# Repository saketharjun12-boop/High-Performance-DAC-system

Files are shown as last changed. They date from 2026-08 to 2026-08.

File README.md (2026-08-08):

# High-Performance Mixed-Signal Headphone DAC

**AK4191EQ + AK4499EX + ESP32-S3 | KiCad | Low-Noise Power | High-Impedance Headphones**

A custom mixed-signal headphone DAC/amplifier designed around the **AK4191EQ digital modulator** and **AK4499EX DAC**, with a focus on low-noise analog power, current-to-voltage conversion, differential analog processing, and high-impedance headphone drive.

> **Project status:** PCB routing is **not complete**. Routing is currently complete **through Stage 2 only**. Later analog/output and remaining power-routing sections are still in progress.

---

## Project Overview

Primary signal chain:

```text
Digital Source
    |
AK4191EQ Digital Modulator
    |
AK4499EX DAC
    |
OPA1612 I/V Conversion
    |
Low-Pass / Differential Summing
    |
OPA1622 Headphone Driver
    |
Output Mute Relay
    |
6.35 mm TRS Headphone Jack
```

Control is provided by an **ESP32-S3**, including I2C configuration and future power-sequencing / relay-control functionality.

---

## Main Components

| Function | Component |
|---|---|
| Digital modulator | AK4191EQ |
| DAC | AK4499EX |
| Controller | ESP32-S3 |
| I/V conversion | OPA1612 |
| Headphone output stage | OPA1622 |
| 5 V to 5.8 V boost | TPS610891 |
| Ultra-low-noise 5VA LDO | LT3045 |
| Bipolar analog supply | TPS65131 |
| Output muting | DPDT relay |
| Output connector | 6.35 mm TRS jack |

---

## Current Project Status

- [x] Overall architecture defined
- [x] Major components selected
- [x] AK4191EQ / AK4499EX architecture
- [x] I/V conversion stage
- [x] Differential / headphone output stage
- [x] Relay-based output mute
- [x] 5VA power architecture
- [x] +/-15 V rail architecture
- [x] Initial power budget
- [x] TPS610891 design calculations
- [x] LT3045 calculations
- [x] Initial +/-15 V / headphone-load budget
- [x] Initial trace-width and via-sizing methodology
- [x] PCB routing through **Stage 3**
- [ ] Remaining PCB routing
- [ ] Final ERC / DRC
- [ ] Final BOM freeze
- [ ] Gerber generation
- [ ] Fabrication
- [ ] Assembly
- [ ] Board bring-up
- [ ] Electrical validation
- [ ] Audio measurements

---

# Power Architecture

```text
USB-C 5 V
   |
   +---- TPS610891 ----> 5.8 V ----> LT3045 ----> 5VA
   |
   +---- TPS65131 ----> +15 V / -15 V
   |
   +---- 3.3 V Regulator ----> ESP32-S3 / clocks / logic
   |
   +---- 1.2 V Regulator ----> AK4191EQ core
```

The **5VA** rail is reserved for the AK4499EX analog/reference supply domains.

---

# Power Budget

The power budget is used to verify regulator capability, estimate upstream USB-C current, and provide starting values for power-trace and via sizing.

## 5VA Analog Rail

| Device / Supply Domain | Typical Current |
|---|---:|
| AK4499EX VDDL + VDDR | 18 mA |
| AK4499EX VREFHL + VREFHR | 46 mA |
| AK4499EX AVDD | 3 mA |
| **AK4499EX subtotal** | **67 mA** |
| LT3045 operating-current provision | ~3 mA |
| **Approximate subtotal** | **~70 mA** |

30% design margin:

```text
70 mA x 1.30 = 91 mA
```

Rounded target:

**5VA design current = 100 mA**

The LT3045 is rated for **500 mA**, so the present load estimate has substantial current margin.

## +15 V and -15 V Rails

| Device | Approximate Current |
|---|---:|
| OPA1622, two channels | 6.76 mA |
| OPA1612 stages | 18 mA |
| **Quiescent subtotal** | **24.76 mA** |

The headphone load adds output-stage rail current. A provisional design target of **75 mA per rail** is derived below.

## 3.3 V Rail

| Component / Function | Peak / Estimated Current |
|---|---:|
| ESP32-S3-MINI-1U peak RF transient assumption | 355 mA |
| AK4191EQ 3.3 V domain(s) | ~5 mA |
| Master-clock oscillators | ~20 mA total |
| 74LVC1G3157 MUX | ~2 mA |
| Pull-ups / passive leakage | ~3 mA |
| **Estimated peak subtotal** | **385 mA** |

Using 50% margin for ESP32 burst current:

```text
385 mA x 1.5 = 577.5 mA
```

Rounded target:

**3.3 V design current = 600 mA**

## 1.2 V Rail

AK4191EQ DVDD core:

- Typical: ~18 mA
- Max / peak design value: ~25 mA

30% margin:

```text
25 mA x 1.30 = 32.5 mA
```

Rounded target:

**1.2 V design current = 40 mA**

---

# TPS610891 Boost Converter Calculations

The TPS610891 creates approximately **5.8 V** from the USB-C 5 V input so the LT3045 has headroom to regulate to 5.0VA.

## Design Targets

| Parameter | Value |
|---|---:|
| VIN | 5.0 V nominal |
| VOUT | 5.8 V |
| IOUT | 100 mA |
| fSW | ~2 MHz |
| Provisional efficiency | 85% |
| Provisional inductor | 2.2 uH |

## Feedback Divider

The PWM feedback reference is approximately 1.212 V.

```text
VOUT = VREF(1 + R1/R2)
```

Choose:

```text
R2 = 100 kOhm
```

Then:

```text
R1 = R2(VOUT/VREF - 1)
R1 = 100k(5.8/1.212 - 1)
R1 ~= 378.5 kOhm
```

Practical selection:

- **R1 ~= 379 kOhm**
- **R2 = 100 kOhm**

## Switching-Frequency Resistor

Using the TPS610891 frequency-setting equation:

```text
RFREQ = 4(1/fSW - tDELAY*VOUT/VIN) / CFREQ
```

with:

```text
fSW = 2 MHz
tDELAY = 86 ns
CFREQ = 24 pF
VOUT = 5.8 V
VIN = 5.0 V
```

Calculated:

**RFREQ ~= 66.7 kOhm**

## Average Inductor Current

```text
IDC = (VOUT*IOUT)/(VIN*eta)
IDC = (5.8*0.1)/(5*0.85)
IDC ~= 136.5 mA
```

## Inductor Ripple Current

```text
IPP = 1 / [L(1/(VOUT-VIN) + 1/VIN)fSW]
```

For L = 2.2 uH:

**IPP ~= 157 mA p-p**

## Peak Inductor Current

```text
IL,peak = IDC + IPP/2
IL,peak = 136.5 mA + 78.5 mA
IL,peak ~= 215 mA
```

Worst-case inductance check using a 30% reduction:

```text
Lmin = 2.2 uH x 0.7 = 1.54 uH
```

A shielded power inductor rated around **1 A or higher** provides generous margin relative to the present calculated peak.

## Equivalent Output Load Resistance

```text
RO = VOUT/IOUT = 5.8/0.1 = 58 Ohm
```

**RO = 58 Ohm**

## Duty Cycle

Using the small-signal equation:

```text
D = 1 - (VIN*eta)/VOUT
D = 1 - (5*0.85)/5.8
D ~= 0.267
```

**D ~= 26.7%**

## Provisional Compensation Assumptions

```text
CO effective = 45 uF
RESR = 3 mOhm
L = 2.2 uH
fSW = 2 MHz
eta = 85%
IOUT = 100 mA
```

These values are provisional until the final capacitor and inductor part numbers are selected.

## Output Pole

```text
fP = 2/(2*pi*RO*CO)
fP ~= 122 Hz
```

## ESR Zero

```text
fESRZ = 1/(2*pi*RESR*CO)
fESRZ ~= 1.18 MHz
```

## Right-Half-Plane Zero

```text
fRHPZ = RO(1-D)^2/(2*pi*L)
fRHPZ ~= 2.25 MHz
```

## Crossover Frequency

Guideline:

```text
fC <= min(fSW/10, fRHPZ/5)
```

```text
fSW/10 = 200 kHz
fRHPZ/5 ~= 450 kHz
```

Provisional crossover:

**fC = 200 kHz**

## Compensation Resistor R5

```text
R5 = [2*pi*VOUT*Rsense*fC*CO] / [(1-D)*VREF*GEA]
```

Using:

```text
Rsense = 0.08 Ohm
VREF = 1.212 V
GEA = 190 uS
```

Calculated:

**R5 ~= 155.5 kOhm**

Practical provisional values:

- 154 kOhm
- 158 kOhm

## Compensation Capacitor C5

```text
C5 = RO*CO/(2*R5)
C5 ~= 8.39 nF
```

Practical provisional value:

**C5 ~= 8.2 nF**

## Compensation Capacitor C6

```text
C6 = RESR*CO/R5
C6 ~= 0.87 pF
```

Because the calculated value is below 10 pF:

**C6 = DNP / Open**

> The compensation network is provisional and should be recalculated using the final inductor, effective output capacitance, capacitor ESR, switching frequency, efficiency, and load.

---

# LT3045 5VA Rail Calculations

Architecture:

```text
5.8 V --> LT3045 --> 5.0VA
```

## SET Resistor

The SET pin sources approximately 100 uA.

```text
RSET = VOUT/ISET
RSET = 5.0/(100 uA)
RSET = 50 kOhm
```

Practical precision value:

**RSET = 49.9 kOhm**

## LDO Dissipation

At the 100 mA design target:

```text
PLDO = (VIN-VOUT)IOUT
PLDO = (5.8-5.0)(0.1)
PLDO = 0.08 W
```

## Power-Good Divider

The PGFB comparator threshold is approximately 300 mV.

Desired Power Good threshold:

```text
VTRIP ~= 4.5 V
```

Choose:

```text
RBOTTOM = 49.9 kOhm
```

Then:

```text
RTOP = RBOTTOM(VTRIP/VPGFB - 1)
RTOP = 49.9k(4.5/0.3 - 1)
RTOP ~= 698.6 kOhm
```

Practical values:

- **RTOP ~= 700 kOhm**
- **RBOTTOM = 49.9 kOhm**

## PG Pull-Up

For ESP32 3.3 V logic:

**RPG = 10 kOhm to 3.3 V**

## Provisional LT3045 Capacitors

- Input: **10 uF + 100 nF**
- SET: **4.7 uF** optional low-noise capacitor
- Output: **22 uF + 100 nF**

Final values should be verified against the final LT3045 implementation.

---

# TPS65131 +/-15 V Rail Calculations

Current design targets:

- **+15 V, 75 mA**
- **-15 V, 75 mA**

## Output Power

```text
POUT = 15I+15 + 15I-15
POUT = 15(0.075) + 15(0.075)
POUT = 2.25 W
```

## 5 V Input-Power Estimate

Assume provisional efficiency:

```text
eta = 80%
```

Then:

```text
PIN = POUT/eta
PIN = 2.25/0.8
PIN = 2.8125 W
```

Input current from 5 V:

```text
IIN,5V = PIN/5
IIN,5V = 2.8125/5
IIN,5V ~= 563 mA
```

**Provisional TPS65131 5 V input requirement ~= 0.56 A**

---

# Headphone Load Calculations

Target class: high-impedance headphones such as a nominal **300 Ohm** load.

The AK4499EX documentation indicates approximately:

- **4.6 Vrms** after individual I/V conversion around signal common
- approximately **9.2 Vrms** after external differential summing

## RMS Headphone Current

```text
IRMS = VRMS/RHP
IRMS = 9.2/300
IRMS ~= 30.7 mA/channel
```

## Peak Current

```text
IPEAK = sqrt(2)*IRMS
IPEAK ~= 43.4 mA/channel
```

## Output Power

```text
POUT = VRMS^2/RHP
POUT = 9.2^2/300
POUT ~= 0.282 W/channel
```

## Approximate Rail-Current Contribution

For a sinusoidal class-AB approximation:

```text
Irail,load ~= IPEAK/pi
Irail,load ~= 13.8 mA/channel
```

Stereo:

```text
Irail,load,stereo ~= 27.6 mA/rail
```

Add amplifier quiescent current:

```text
24.76 + 27.6 = 52.36 mA/rail
```

Apply 30% margin:

```text
52.36 x 1.30 = 68.1 mA/rail
```

Rounded design target:

**75 mA per rail**

---

# Trace Width Calculations

Power-trace width is based on current, copper thickness, route length, acceptable voltage drop, temperature rise, and fabrication limits.

Copper resistivity:

```text
rho ~= 1.72e-8 Ohm*m
```

For 1 oz copper:

```text
t ~= 35 um
```

## Trace Resistance

```text
Rtrace = rho*L/(w*t)
```

## Voltage Drop

```text
Vdrop = I*Rtrace
```

## Power Loss

```text
Ploss = I^2*Rtrace
```

## Width From Voltage-Drop Requirement

```text
w = rho*L*I/(t*Vdrop,max)
```

## 5VA Example

Assume:

```text
I = 0.1 A
L = 50 mm = 0.05 m
Vdrop,max = 5 mV = 0.005 V
t = 35 um
```

Calculated:

```text
w ~= 0.49 mm
```

Practical provisional width:

**5VA = 0.50 mm**

## +/-15 V Example

Using:

```text
I = 75 mA
L = 50 mm
Vdrop,max = 5 mV
```

Calculated width is approximately 0.37 mm.

Practical provisional choice:

**+15 V / -15 V = 0.50 mm**

## 3.3 V Main Distribution

With a 600 mA design target, the main 3.3 V trunk is provisionally assigned:

**3.3 V main = ~0.8 mm**

Individual low-current branches do not need to remain 0.8 mm.

## USB 5 V

Provisional initial class:

**USB 5 V = 1.0-1.2 mm**

## Headphone Output

The 300 Ohm load current is modest, so the wider trace primarily reduces added series resistance and provides robust routing.

**Headphone output = ~0.8 mm**

---

# Via Sizing

## Standard Signal Via

```text
Diameter: 0.60 mm
Drill:    0.30 mm
```

Used for digital signals, I2C, I2S, ordinary analog signals, ground stitching, and low-current branches.

## Power Via

```text
Diameter: 0.80 mm
Drill:    0.40 mm
```

Used for 5VA, +/-15 V, and main 3.3 V power transitions.

## Higher-Current USB Via

```text
Diameter: 1.00 mm
Drill:    0.50 mm
```

or multiple smaller vias in parallel.

Multiple vias are preferred where higher current or lower inductance is desired.

---

# Net Classes

| Net Class | Clearance | Width | Via | Drill |
|---|---:|---:|---:|---:|
| Signal | 0.20 mm | 0.20 mm | 0.60 mm | 0.30 mm |
| Clock | 0.20 mm | 0.20 mm | 0.60 mm | 0.30 mm |
| I2S | 0.20 mm | 0.20 mm | 0.60 mm | 0.30 mm |
| Analog Signal | 0.20 mm | 0.20-0.25 mm | 0.60 mm | 0.30 mm |
| 5VA | 0.20 mm | 0.50 mm | 0.80 mm | 0.40 mm |
| +15 V | 0.20 mm | 0.50 mm | 0.80 mm | 0.40 mm |
| -15 V | 0.20 mm | 0.50 mm | 0.80 mm | 0.40 mm |
| 3V3 Main | 0.20 mm | ~0.80 mm | 0.80 mm | 0.40 mm |
| 1V2 | 0.20 mm | 0.30-0.50 mm | 0.60 mm | 0.30 mm |
| USB Power | 0.20-0.25 mm | 1.0-1.2 mm | 1.00 mm | 0.50 mm |
| Headphone Out | 0.20 mm | 0.80 mm | 0.80 mm | 0.40 mm |

These values should be checked against the final PCB manufacturer's design rules.

---

# Critical Signal Lengths

| Connection | Target |
|---|---:|
| AK4499EX IOUT to OPA1612 input | ideally <5-10 mm |
| OPA1612 feedback loop | ideally <5 mm |
| OPA1622 feedback / summing network | ideally <5-10 mm |
| 100 nF decoupling capacitor | approximately 1-3 mm from supply pin where practical |
| TPS610891 SW to inductor | minimum practical length |
| TPS65131 switch nodes | minimum practical length |
| LT3045 SET / OUTS | preferably <5-10 mm |
| MCLK | preferably <25-30 mm |
| BCLK / LRCK / SDATA | short; ~10 mm BCLK is excellent |

---

# Repository Folders

```text
High_Performance_DAC_Portfolio/
|
|-- README.md
|-- PCB_Files/
|-- Schematics/
|-- Images/
|-- Handwritten_Calculations/
|-- Datasheets/
|-- BOM/
`-- Gerbers/
```

## Schematic Images and PCB progress

## Total Circuit
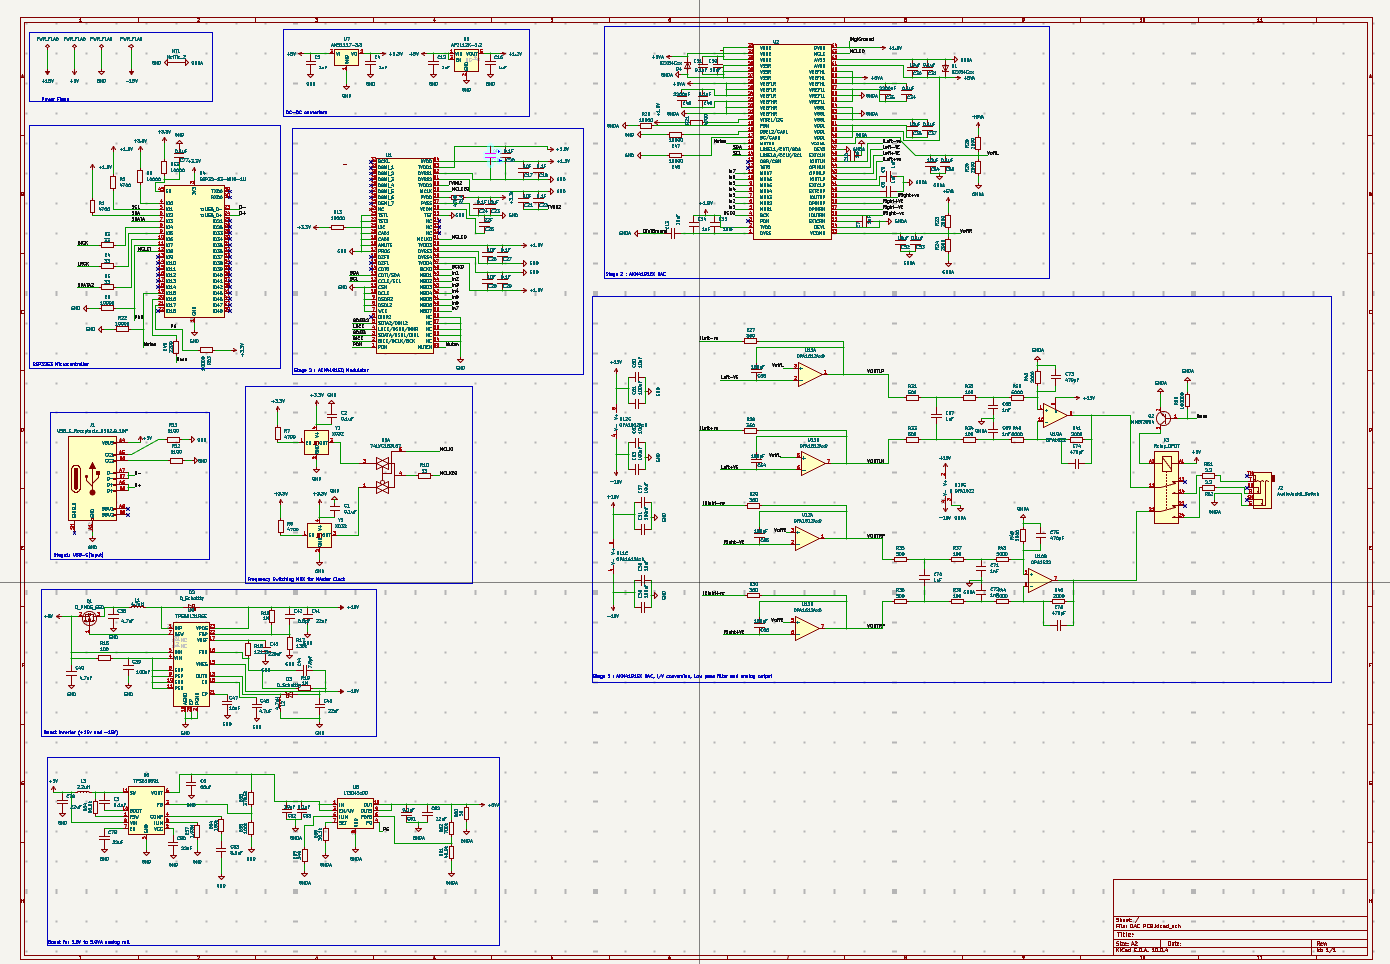
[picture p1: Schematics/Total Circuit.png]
Total Circuit


## Stage 1
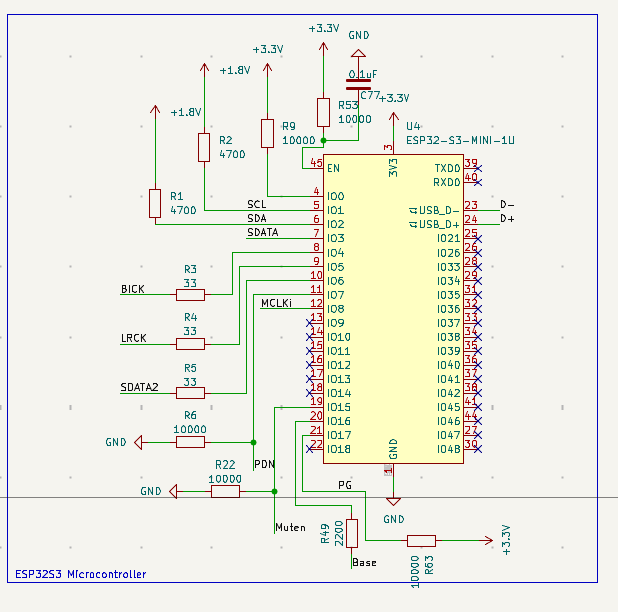
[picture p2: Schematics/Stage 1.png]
Stage 1


## Stage 2
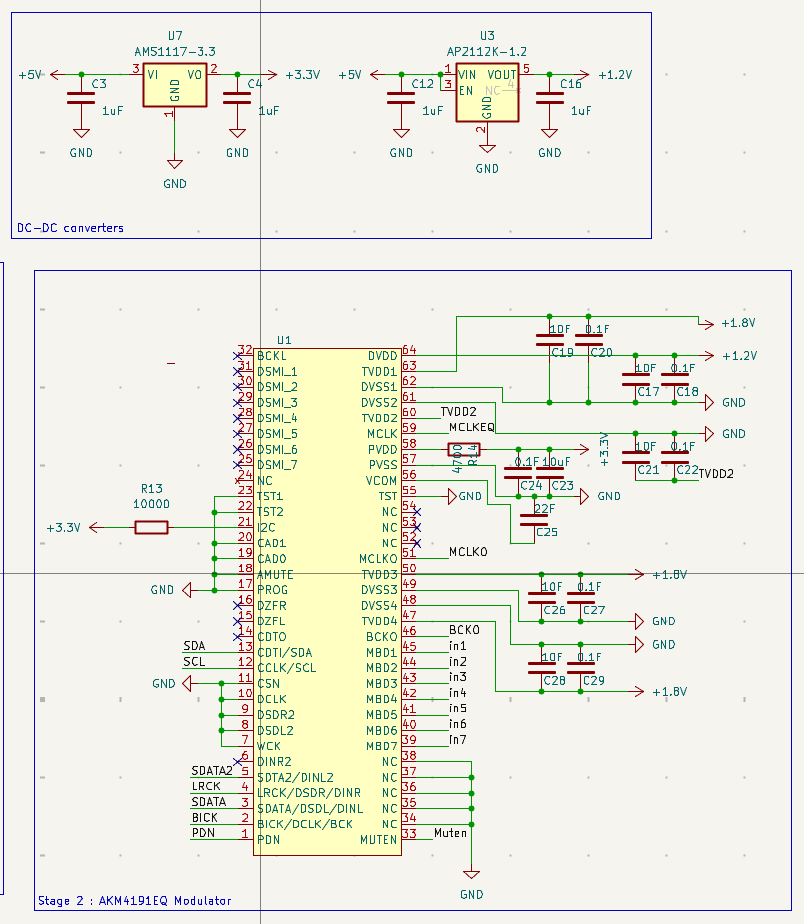
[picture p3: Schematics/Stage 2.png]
Stage 2


## Stage 3
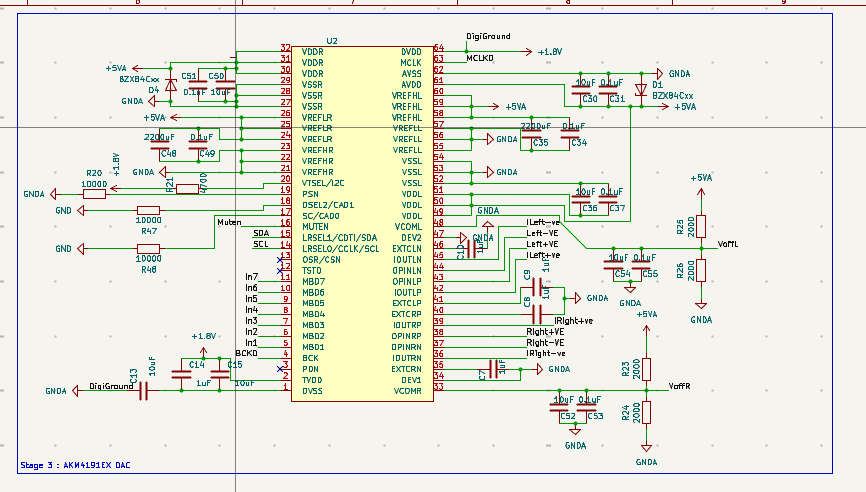
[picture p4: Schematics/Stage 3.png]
Stage 3


## Stage 4
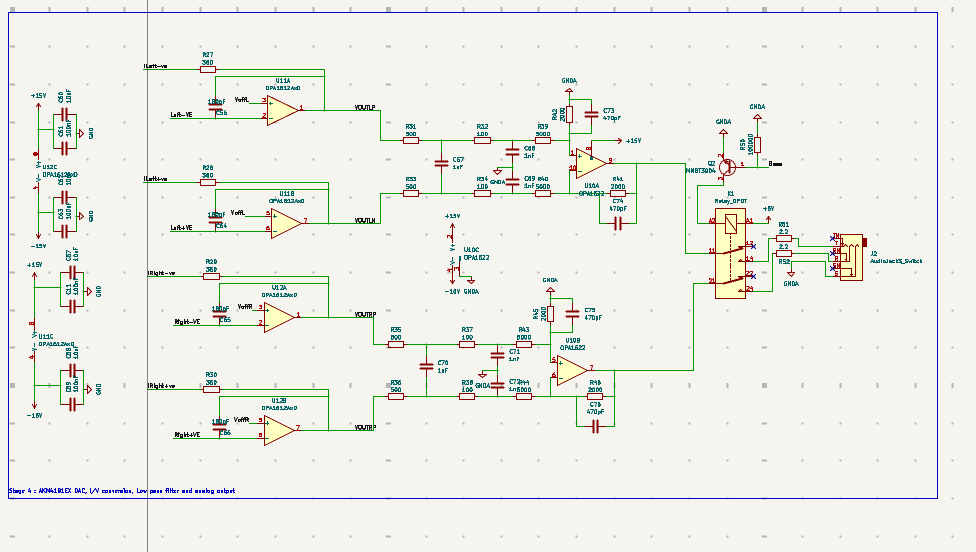
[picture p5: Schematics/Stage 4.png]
Stage 4


## USB-C Interface
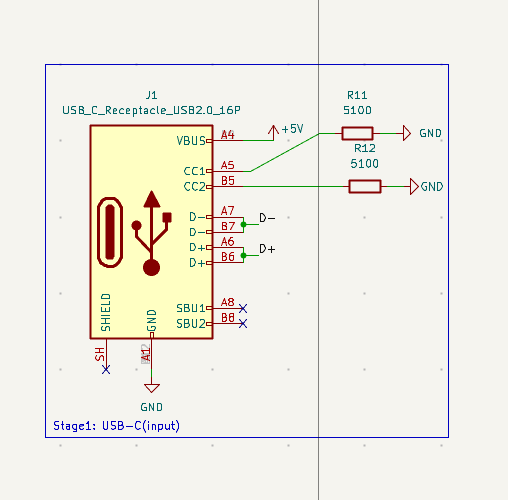
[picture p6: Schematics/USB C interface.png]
USB-C Interface


## Boost Inverter and Boost Regulator
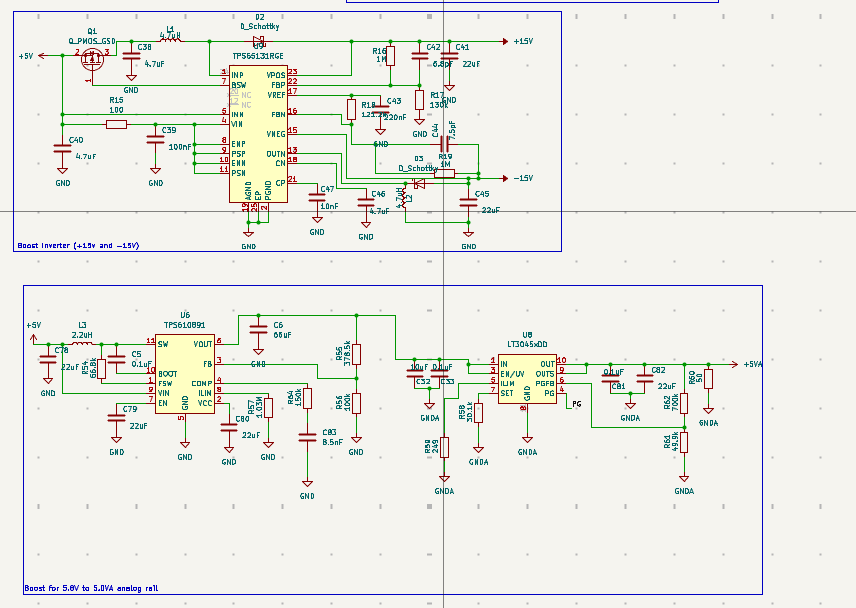
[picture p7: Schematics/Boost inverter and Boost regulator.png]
Boost Inverter and Boost Regulator


## PCB progress Stage 1 and Stage 2
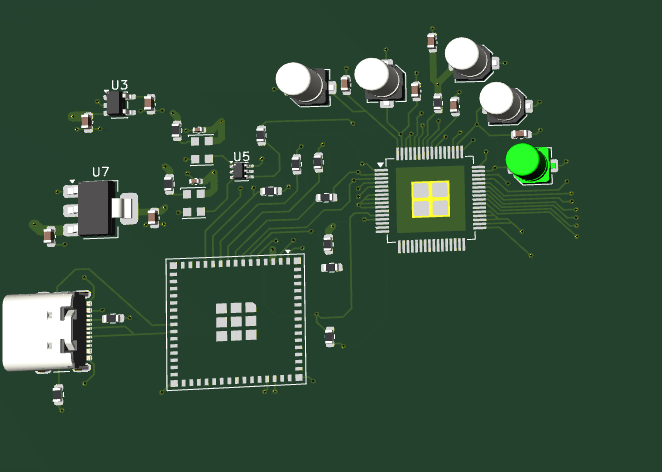
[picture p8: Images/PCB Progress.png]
PCB Progress

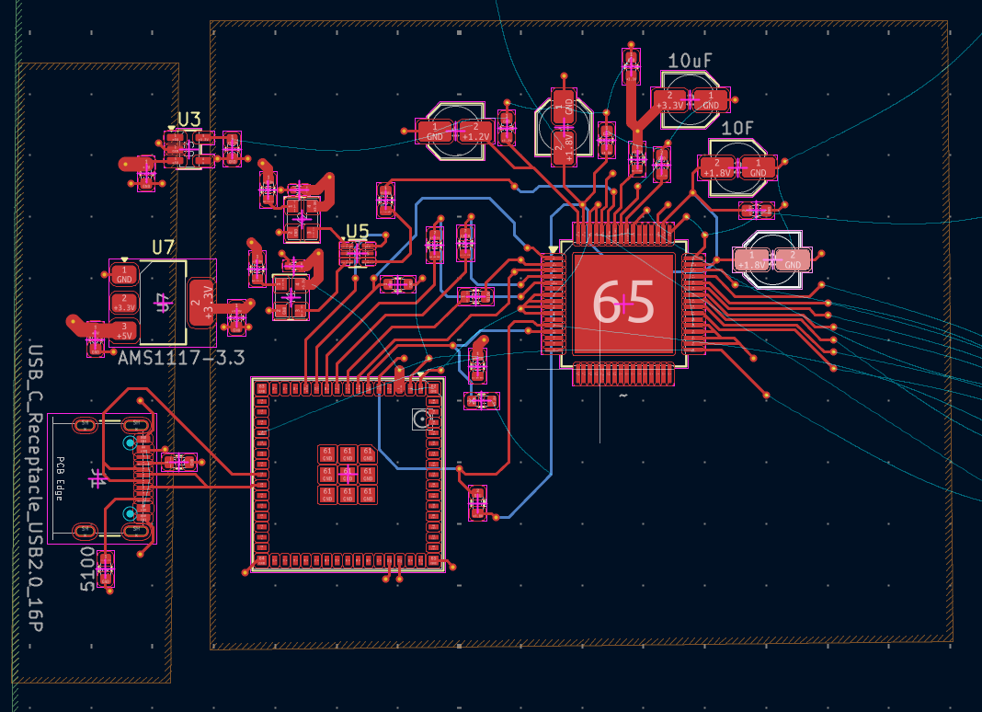
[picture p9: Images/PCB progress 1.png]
PCB Progress 1


---

# Planned Validation

After fabrication:

- Verify 5.8 V boost output
- Verify 5VA regulation
- Measure 5VA ripple
- Measure +15 V and -15 V ripple
- Verify startup sequencing
- Verify Power Good behavior
- Verify relay mute timing
- Measure DAC DC offsets
- Verify maximum headphone output
- Measure frequency response
- Measure FFT / noise floor
- Measure THD+N
- Measure output impedance
- Evaluate thermal performance

---

# Future Work

- Complete PCB routing after Stage 2
- Recalculate power-trace voltage drop using actual routed lengths
- Freeze exact capacitor and inductor manufacturer part numbers
- Recalculate TPS610891 compensation using final effective capacitance and ESR
- Perform final regulator thermal checks
- Run ERC and DRC
- Generate Gerbers
- Fabricate and assemble the PCB
- Perform bring-up and measurement
- Add measurement plots and final PCB renders to this README

---

# Disclaimer

This repository documents an **in-progress engineering project**.

The present PCB routing is not complete, and the design has not yet been fabricated or electrically validated. Several calculated values are provisional and will be updated after the final BOM, PCB routing, and measured prototype data are available.

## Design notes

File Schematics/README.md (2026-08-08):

Place editable KiCad schematic/project files here.

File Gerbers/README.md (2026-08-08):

Add Gerbers and fabrication outputs here after PCB routing and final DRC are complete.

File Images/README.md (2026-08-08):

Upload schematic stages, PCB progress screenshots, PCB renders, and final hardware photos here.

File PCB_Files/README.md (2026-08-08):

Place KiCad PCB/project files here.

Current PCB routing is incomplete and only complete through Stage 3.

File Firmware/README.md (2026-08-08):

# Firmware

Reserved for ESP32-S3 control, I2C configuration, sequencing, and relay mute firmware.

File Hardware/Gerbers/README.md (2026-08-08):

# Gerbers

Add after routing and final DRC.

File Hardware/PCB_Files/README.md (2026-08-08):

# PCB Files

Upload KiCad PCB files here.

**Status:** PCB routing is incomplete and currently complete through Stage 3 only.

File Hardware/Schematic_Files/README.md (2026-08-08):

# Schematic Files

Upload editable KiCad schematic/project files here.

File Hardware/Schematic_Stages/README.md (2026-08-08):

# Schematic Stage Images

Upload your exported schematic screenshots using these exact filenames so the root README displays them automatically:

- `stage_1.png`
- `stage_2.png`
- `stage_3.png`
- `power_stage.png`
- `analog_output_stage.png`

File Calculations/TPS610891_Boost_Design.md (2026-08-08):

# TPS610891 Boost Converter Calculations

## Design Targets
- VIN = 5.0 V
- VOUT = 5.8 V
- IOUT = 100 mA
- fSW ~= 2 MHz
- L = 2.2 uH provisional
- efficiency assumption = 85%

## Feedback Divider
VOUT = VREF(1 + R1/R2)

Using VREF = 1.212 V and R2 = 100 kOhm:

R1 ~= 378.5 kOhm

**Practical: R1 ~= 379 kOhm, R2 = 100 kOhm**

## Switching Frequency Resistor
Using the datasheet equation with:
- fSW = 2 MHz
- tDELAY = 86 ns
- CFREQ = 24 pF
- VOUT = 5.8 V
- VIN = 5.0 V

**RFREQ ~= 66.7 kOhm**

## Average Inductor Current
IDC = (VOUT * IOUT)/(VIN * eta)

IDC ~= 136.5 mA

## Inductor Ripple
IPP = 1/[L(1/(VOUT-VIN)+1/VIN)fSW]

**IPP ~= 157 mA p-p**

## Peak Inductor Current
IL,PEAK = IDC + IPP/2

**IL,PEAK ~= 215 mA nominal**

## Equivalent Load Resistance
RO = VOUT/IOUT = 5.8/0.1

**RO = 58 Ohm**

## Duty Cycle
D = 1 - (VIN * eta)/VOUT

**D ~= 26.7%**

## Provisional Loop Compensation

Assumptions:
- CO effective = 45 uF
- RESR = 3 mOhm
- Rsense = 0.08 Ohm
- VREF = 1.212 V
- GEA = 190 uS
- fC = 200 kHz

Calculated:
- fP ~= 122 Hz
- fESRZ ~= 1.18 MHz
- fRHPZ ~= 2.25 MHz
- R5 ~= 155.5 kOhm
- C5 ~= 8.39 nF
- C6 ~= 0.87 pF -> DNP / open

These values are provisional until exact capacitor and inductor part numbers are selected.

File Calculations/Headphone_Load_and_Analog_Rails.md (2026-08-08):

# Headphone Load / Analog Rail Calculations

Target load: nominal 300 ohm high-impedance headphone.

For 9.2 Vrms:

I_RMS = 9.2/300 = 30.7 mA/channel

I_PEAK = sqrt(2)*30.7 = 43.4 mA/channel

P_OUT = 9.2^2/300 ~= 0.282 W/channel

Approximate class-AB rail-load contribution:

I_rail ~= I_PEAK/pi ~= 13.8 mA/channel

Stereo ~= 27.6 mA/rail

Adding provisional amplifier quiescent current:

24.76 + 27.6 ~= 52.36 mA/rail

With 30% margin:

52.36 * 1.3 ~= 68.1 mA/rail

**Provisional rail target: 75 mA on +15 V and 75 mA on -15 V**

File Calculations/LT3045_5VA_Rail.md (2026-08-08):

# LT3045 5VA Rail

## Architecture
TPS610891 5.8 V --> LT3045 --> 5.0VA

## SET Resistor
RSET = VOUT / 100 uA

RSET = 5.0 / 100 uA = 50 kOhm

**Practical: 49.9 kOhm**

## LDO Dissipation
At 5.8 V input, 5.0 V output, 100 mA:

P = (5.8 - 5.0)*0.1 = 0.08 W

## Power Good Divider
PGFB typical threshold ~= 300 mV

For a ~4.5 V Power Good threshold, choosing RLOW = 49.9 kOhm:

RHIGH ~= 698.6 kOhm

**Practical: RHIGH ~= 700 kOhm, RLOW = 49.9 kOhm**

PG pull-up to ESP32 3.3 V:

**RPG = 10 kOhm**

## Provisional Capacitors
- Input: 10 uF + 100 nF
- SET: 4.7 uF optional
- Output: 22 uF + 100 nF

Final values should be verified against the final LT3045 implementation and effective capacitance.

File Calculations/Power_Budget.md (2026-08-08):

# Power Budget

## 5VA Analog Rail

| Load | Current |
|---|---:|
| AK4499EX VDDL + VDDR | 18 mA typ. |
| AK4499EX VREFHL + VREFHR | 46 mA typ. |
| AK4499EX AVDD | 3 mA typ. |
| AK4499EX subtotal | 67 mA |
| LT3045 operating-current provision | ~3 mA |
| Approximate load before margin | ~70 mA |
| 30% margin | ~91 mA |
| **Design target** | **100 mA** |

## +15 V / -15 V Rails

| Load | Current |
|---|---:|
| OPA1612 stages | 18 mA |
| OPA1622, 2 channels | 6.76 mA |
| Quiescent subtotal | 24.76 mA |

For 9.2 Vrms into 300 ohm:

I_RMS = 9.2 / 300 = 30.7 mA/channel

I_PEAK = sqrt(2) * 30.7 = 43.4 mA/channel

Approximate class-AB rail load per channel:

I_rail ~= I_PEAK / pi = 13.8 mA

Stereo contribution ~= 27.6 mA/rail

Total ~= 24.76 + 27.6 = 52.36 mA/rail

With 30% margin ~= 68.1 mA/rail

**Design target: 75 mA per rail**

## 3.3 V Rail

| Load | Estimated Peak |
|---|---:|
| ESP32-S3-MINI-1U | 355 mA |
| AK4191EQ 3.3 V domains | ~5 mA |
| Master clock oscillators | ~20 mA |
| 74LVC1G3157 | ~2 mA |
| Pull-ups / leakage | ~3 mA |
| **Subtotal** | **385 mA** |

Using 50% margin for ESP32 burst current:

385 mA * 1.5 = 577.5 mA

**Design target: 600 mA**

## 1.2 V Rail

AK4191EQ DVDD:
- Typical: ~18 mA
- Max: ~25 mA

25 mA * 1.30 = 32.5 mA

**Design target: 40 mA**

## Upstream TPS65131 5 V Estimate

Using 75 mA on both +15 V and -15 V:

P_OUT = 15(0.075) + 15(0.075) = 2.25 W

Assuming 80% efficiency:

P_IN = 2.25 / 0.80 = 2.8125 W

I_IN,5V = 2.8125 / 5 = 0.5625 A

**Provisional 5 V requirement: ~0.56 A**

## Upstream TPS610891 5 V Estimate

For 5.8 V at 100 mA and 85% efficiency:

I_IN = (5.8 * 0.1)/(5 * 0.85) ~= 0.136 A

**Provisional 5 V requirement: ~136 mA**

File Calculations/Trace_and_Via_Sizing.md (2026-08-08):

# Trace and Via Sizing

## Core Equations

Rtrace = rho*L/(w*t)

Vdrop = I*Rtrace

Ploss = I^2*Rtrace

For 1 oz copper:

t ~= 35 um

rho ~= 1.72e-8 Ohm*m

## Provisional Net Classes

| Class | Width | Via | Drill |
|---|---:|---:|---:|
| Signal | 0.20 mm | 0.60 mm | 0.30 mm |
| Clock / I2S | 0.20 mm | 0.60 mm | 0.30 mm |
| Analog signal | 0.20-0.25 mm | 0.60 mm | 0.30 mm |
| 5VA | 0.50 mm | 0.80 mm | 0.40 mm |
| +15 V / -15 V | 0.50 mm | 0.80 mm | 0.40 mm |
| Main 3.3 V trunk | ~0.8 mm | 0.80 mm | 0.40 mm |
| USB 5 V | ~1.0-1.2 mm | 1.00 mm | 0.50 mm |
| Headphone output | ~0.8 mm | 0.80 mm | 0.40 mm |

Final verification should use actual routed lengths.

## Critical Short Nets
- AK4499EX IOUT --> OPA1612
- OPA1612 feedback loops
- OPA1622 feedback / summing network
- TPS610891 SW
- TPS65131 switch nodes
- 100 nF decoupling loops
- MCLK
- LT3045 SET / OUTS

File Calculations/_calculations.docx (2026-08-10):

Documentation:

Power rating for 5VA:

Chosen regulator: LT3045xDD, MAx output 600ma

Current consumed by 5VA rails:

Device | Typical Current
AK4499EX VDDL + VDDR | 18 mA
AK4499EX VREFHL + VREFHR | 46 mA
AK4499EX AVDD | 3 mA
Subtotal | 67 mA
LT3045 ground current | ~3 mA
Boost converter output current Worst caseTPS610891 | 70 mA 0.18mA
30% design margin | ≈91 mA
Design target | 100 mA

Worst caseTPS610891 0.18mA

Power rating for +15V and -15V rails:

Device | Typical Current
OPA1622 | 6.76 mA(2 channels)
OPA1612 | 18mA
30% design margin | ≈24.76mA
Design target | 25mA

### 1. Component Current Breakdown (3.3V Rail)

Component / Function | Parameter / State | Peak Current (Imax)
ESP32-S3-MINI-1U (U4) | Peak Wi-Fi/BT TX Transients (Assumption) | 355 mA
AK4191EQ Modulator (U1) | Digital DVDD / TVDD2 at 3.3V | ~5 mA
Master Clock Oscillators (Y1, Y2) | Active XO32 Crystal Oscillators | ~20 mA total
74LVC1G3157 MUX (U5A) | Static + Switching Current | ~2 mA
Pull-Up Resistors & Passive Leakage | R9, R53, R7, R8, R13, R63 | ~3 mA
Total Peak Current | Worst-Case Simultaneous Draw | 385 mA

### 1. Component Current Breakdown (1.2V Rail)

Parameter / Operational Mode | Typical Current (Ityp) | Max / Peak Current (Imax)
AK4191EQ DVDD (1.2V Core) | ~18 mA(PDF) | ~25 mA(PDF)

# Power Budget

The purpose of the power budget is to estimate the maximum current required by each voltage rail, verify regulator sizing, and determine the total current ultimately required from the 5 V USB-C input.

The board contains the following main rails:

USB-C 5 V

│

├── TPS610891 → 5.8 V → LT3045 → 5VA

│

├── TPS65131 → +15 V / -15 V

│

├── 3.3 V regulator → ESP32-S3 + digital circuitry

│

└── AP2112K-1.2 → 1.2 V digital core

# 1. 5VA Analog Rail

### Regulator

LT3045 ultra-low-noise LDO

VOUT=5.0V

Maximum regulator output capability:

IOUT,max=500mA

The LT3045 is supplied from approximately 5.8 V generated by the TPS610891 boost converter.

## AK4499EX 5VA loads

Device / Supply Domain | Typical Current
AK4499EX VDDL + VDDR | 18 mA
AK4499EX VREFHL + VREFHR | 46 mA
AK4499EX AVDD | 3 mA
AK4499EX subtotal | 67 mA

Therefore:

I5VA,load≈67mA

Add approximately 3 mA provisionally for LT3045 operating/ground current:

ILT3045,in≈67+3 ILT3045,in≈70mA

The TPS610891 also consumes approximately 180 µA maximum from its VOUT pin under the specified no-load condition.

70mA+0.18mA=70.18mA

### 30% design margin

Idesign=70.18mA×1.30 Idesign≈91.2mA

Round upward:

I5VA,design=100mA

### Result

Parameter | Value
Estimated operating current | ~70 mA
Current with 30% margin | ~91 mA
Design target | 100 mA
LT3045 capability | 500 mA

The LT3045 therefore has a substantial current margin.

# 2. TPS610891 5 V Input Requirement

The TPS610891 supplies approximately:

VOUT=5.8V

at a design current of:

IOUT=100mA

Assume:

ηboost=85%

Input current is estimated from conservation of power:

IIN=VINηVOUTIOUT IIN=5(0.85)5.8(0.1) I5V,TPS610891≈136mA

This 136 mA, rather than the converter's multi-amp switch rating, is what belongs in the overall USB power budget.

# 3. +15 V and −15 V Analog Rails

The ±15 V rails power the analog I/V and headphone amplifier stages.

Current-consuming devices:

Device | Supply Current
OPA1612 I/V stages | 18 mA
OPA1622 stereo amplifier | 6.76 mA
Quiescent subtotal | 24.76 mA per rail

However, this is only the idle amplifier current. The headphone load must also be included.

## Headphone load

Target headphone:

Sennheiser HD600 class

Nominal impedance:

RHP=300Ω

Maximum intended output:

VHP=9.2VRMS

RMS headphone current per channel:

IHP,RMS=RHPVRMS IHP,RMS=3009.2 IHP,RMS≈30.7mA

Peak headphone current:

IHP,peak=2IHP,RMS IHP,peak=1.414(30.7) IHP,peak≈43.4mA

For a sinusoidal class-AB output stage, approximate average load current drawn from each supply rail per channel:

Irail,load≈πIpeak Irail,load≈π43.4 Irail,load≈13.8mA

Stereo:

Irail,load,stereo=2(13.8) Irail,load,stereo≈27.6mA

Now add quiescent amplifier current:

I+15=24.76+27.6 I+15≈52.36mA

Similarly:

I−15≈52.36mA

### Add 30% design margin

52.36×1.30=68.1mA

Round upward:

I+15,design=75mA I−15,design=75mA

### ±15 V summary

Parameter | +15 V | −15 V
Amplifier quiescent current | 24.76 mA | 24.76 mA
Stereo headphone contribution | ~27.6 mA | ~27.6 mA
Estimated operating requirement | ~52.4 mA | ~52.4 mA
30% margin | ~68.1 mA | ~68.1 mA
Design target | 75 mA | 75 mA

# 4. TPS65131 5 V Input Requirement

The TPS65131 produces both ±15 V rails.

Maximum design output power:

P±15=15I+15+15I−15

Using:

I+15=I−15=75mA P±15=15(0.075)+15(0.075) P±15=2.25W

Assume approximately 80% converter efficiency:

η=0.80

Required 5 V input power:

PIN=0.802.25 PIN=2.8125W

Therefore:

I5V,TPS65131=52.8125 I5V,TPS65131≈563mA

Use approximately:

0.56A

in the USB/5 V rail budget.

# 5. 3.3 V Rail

Your current component estimate is:

Component | Maximum / Peak Current
ESP32-S3-MINI-1U | 355 mA
AK4191EQ 3.3 V supply domain(s) | ~5 mA
Master-clock oscillators | ~20 mA
74LVC1G3157 | ~2 mA
Pull-ups / leakage | ~3 mA
Total | 385 mA

One terminology correction: do not label the AK4191 3.3 V entry DVDD if DVDD is the 1.2 V core rail in your design. Label the exact 3.3 V supply pin(s) so DVDD is not accidentally counted twice.

Because the ESP32 can produce short current transients, use a larger margin than the analog rails.

Use 50%:

I3.3V,design=385mA×1.5 I3.3V,design=577.5mA

Round upward:

I3.3V,design=600mA

If the 1.2 V regulator is powered from the 3.3 V rail, its input current must also be added here. In that case, use approximately:

600mA+40mA≈640mA

as the conservative 3.3 V source requirement.

# 6. 1.2 V Rail

The AK4191EQ core consumes:

Parameter | Typical | Maximum
AK4191EQ DVDD | ~18 mA | ~25 mA

Use the maximum current:

I1.2,max=25mA

Add 30%:

I1.2,design=25×1.30 I1.2,design=32.5mA

Round upward:

I1.2V,design=40mA

This is far below the AP2112K's available output-current capability.

### Important upstream accounting

If:

3.3 V → AP2112K-1.2 → 1.2 V

then the approximately 40 mA AP2112 input current is already part of the 3.3 V regulator load.

Do not add it to USB current a second time.

If instead:

5 V → AP2112K-1.2 → 1.2 V

then approximately 40 mA should be included directly in the 5 V budget.

# 7. Relay / Direct 5 V Loads

Your mute relay is another direct load.

Find its coil resistance or rated coil current from its datasheet.

If the coil resistance is given:

Irelay=RcoilVcoil

Example:

V=5V,R=167Ω Irelay≈30mA

Enter the actual relay value when the part is finalized.

# 8. Total USB-C 5 V Budget

Using the numbers currently established:

5 V Load | Design Input Current
TPS610891 → 5VA system | ~136 mA
TPS65131 → ±15 V | ~563 mA
3.3 V regulator | ~600 mA
1.2 V regulator if directly from 5 V | ~40 mA
Relay | TBD
Other direct 5 V loads | TBD

Ignoring the relay temporarily:

IUSB=0.136+0.563+0.600+0.040 IUSB≈1.339A

If the AP2112 is powered from 3.3 V instead, don't add its 40 mA separately; it is already included upstream.

So your current estimated full-load USB requirement is roughly:

1.3–1.4A

before the relay and miscellaneous loads.

Add approximately 20% overall system margin:

1.34×1.20≈1.61A

Therefore I would design the USB-C power input around at least:

5V, 2A

rather than assuming 4–6 A.

# Final Power Budget Summary

Rail | Estimated / Peak Load | Design Margin | Design Target
5VA | ~70 mA | 30% | 100 mA
+15 V | ~52.4 mA | 30% | 75 mA
−15 V | ~52.4 mA | 30% | 75 mA
3.3 V | 385 mA | 50% | 600 mA
1.2 V | 25 mA | 30% | 40 mA
USB-C 5 V | ~1.34 A + relay | ~20% system margin | ≈2 A source recommended

Net Class | Current | Via Diameter | Drill
Digital (GPIO, I²C, I²S) | <20 mA | 0.60 mm | 0.30 mm
Analog signals | <20 mA | 0.60 mm | 0.30 mm
1.2 V rail | ~40 mA | 0.60 mm | 0.30 mm
5VA rail | ~100 mA | 0.60 mm | 0.30 mm
+15 V / −15 V rails | ~75 mA | 0.60 mm | 0.30 mm
ESP32 3.3 V branch | ~355 mA | 0.80 mm | 0.40 mm
USB 5 V main input | 1–2 A | 1.00 mm | 0.50 mm or two 0.60/0.30 mm vias in parallel
Ground stitching | — | 0.60 mm | 0.30 mm

Net Class | Clearance | Track Width | Via Size | Via Hole | Used For
Signal | 0.20 mm | 0.20 mm | 0.60 mm | 0.30 mm | GPIO, I²C, control signals
Clock | 0.20 mm | 0.20 mm | 0.60 mm | 0.30 mm | MCLK, BCLK, LRCK
I2S | 0.20 mm | 0.20 mm | 0.60 mm | 0.30 mm | SDIN, SDOUT
USB_Power | 0.30 mm | 1.20 mm | 1.00 mm | 0.50 mm | USB-C 5V input
5VA | 0.20 mm | 0.50 mm | 0.80 mm | 0.40 mm | LT3045 analog rail
3V3_Main | 0.20 mm | 0.80 mm | 0.80 mm | 0.40 mm | Main 3.3V trunk
3V3_Branch | 0.20 mm | 0.30 mm | 0.60 mm | 0.30 mm | Oscillators, AK4191, logic
1V2 | 0.20 mm | 0.30 mm | 0.60 mm | 0.30 mm | AK4191 core
+15V | 0.20 mm | 0.50 mm | 0.80 mm | 0.40 mm | Analog amplifier supply
-15V | 0.20 mm | 0.50 mm | 0.80 mm | 0.40 mm | Analog amplifier supply
HP_OUT | 0.20 mm | 0.80 mm | 0.80 mm | 0.40 mm | Left/Right headphone outputs
AGND | — | Plane | 0.60 mm | 0.30 mm | Analog ground plane
DGND | — | Plane | 0.60 mm | 0.30 mm | Digital ground plane

Rule of thumb design rules:

:

Area | Suggested placement
General pull-ups / GPIO resistors | 1–3 mm apart is fine
I²C pull-ups | No critical spacing; keep near the bus/controller
OPA1612 I/V feedback parts | Very close to op-amp, ~1–2 mm if possible
OPA1622 differential/summing resistors | Close together and close to op-amp
LPF resistors/capacitors | Keep the whole filter cluster compact
TPS610891 FB/COMP resistors | Very close to FB/COMP pins, away from SW/inductor
LT3045 SET/PGFB resistors | Close to LT3045, referenced to quiet ground
Relay/output resistors | Can be several mm apart; not noise-critical

Capacitor type | Distance from IC pin
100 nF high-frequency decoupling | 1–3 mm ideally
1 µF local decoupling | 2–5 mm
10–22 µF bulk/local rail capacitor | 5–15 mm is usually fine
Switching regulator input/output caps | as close as physically possible

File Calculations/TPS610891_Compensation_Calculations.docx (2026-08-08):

# TPS610891 Boost Converter Compensation Calculations

Provisional design for 5.0 V input, 5.8 V output, 100 mA load

Purpose. This document records the initial small-signal and compensation calculations for the TPS610891 stage that feeds an LT3045. The values are provisional until the exact output-capacitor part number, DC-bias derating, ESR, inductor, and measured loop response are confirmed. The calculation sequence follows the Texas Instruments TPS61089/TPS610891 datasheet, Equations 12–19.

# 1. Design Inputs and Assumptions

Parameter | Value | Reason / source
Input voltage, VIN | 5.0 V | USB-C 5 V nominal
Boost output voltage, VOUT | 5.8 V | Provides headroom for LT3045 regulating to 5.0 V
Design output current, IOUT | 0.10 A | 5VA load plus regulator current and margin
Switching frequency, fSW | 2.0 MHz | Selected design target
Inductor, L | 2.2 µH | Initial selected value
Assumed efficiency, η | 0.85 | Conservative provisional estimate
Effective output capacitance, CO | 45 µF | Assumed after DC-bias derating of 3 × 22 µF ceramics
Equivalent output-capacitor ESR, RESR | 3 mΩ | Provisional parallel equivalent
FB reference voltage, VREF | 1.212 V | TPS610891 typical PWM reference
Error-amplifier transconductance, GEA | 190 µS | TPS610891 typical value
Equivalent current-sense resistance, Rsense | 0.08 Ω | TPS610891 datasheet model value

# 2. Output Load Resistance

The small-signal model uses the output load resistance:

Rₒ = VOUT / IOUT = 5.8 V / 0.10 A = 58 Ω

Result: Rₒ = 58 Ω.

# 3. Effective Duty Cycle

Using the datasheet expression that includes assumed conversion efficiency:

D = 1 − (VIN × η / VOUT)

D = 1 − (5.0 × 0.85 / 5.8) = 0.267

Result: D ≈ 0.267, or 26.7%.

# 4. Output Pole

fP = 2 / (2π × Rₒ × Cₒ)

fP = 2 / (2π × 58 × 45 µF) ≈ 122 Hz

Result: fP ≈ 122 Hz.

# 5. Capacitor ESR Zero

fESRZ = 1 / (2π × RESR × Cₒ)

fESRZ = 1 / (2π × 0.003 × 45 µF) ≈ 1.18 MHz

Result: fESRZ ≈ 1.18 MHz. The high value is expected with low-ESR ceramic capacitors.

# 6. Right-Half-Plane Zero

fRHPZ = Rₒ × (1 − D)² / (2π × L)

fRHPZ = 58 × (1 − 0.267)² / (2π × 2.2 µH) ≈ 2.25 MHz

Result: fRHPZ ≈ 2.25 MHz.

# 7. Crossover Frequency Selection

The datasheet recommends keeping crossover below the smaller of one-tenth of the switching frequency and one-fifth of the RHP zero:

fC ≤ min(fSW / 10, fRHPZ / 5)

fSW / 10 = 200 kHz

fRHPZ / 5 ≈ 451 kHz

Selected provisional fC = 200 kHz

Caution: 200 kHz is the maximum value allowed by this simple guideline, not a guaranteed optimum. A more conservative first-pass target such as 100–150 kHz may provide more phase margin and should be considered during simulation or bench verification.

# 8. Compensation Resistor R5

R5 = [2π × VOUT × Rsense × fC × Cₒ] / [(1 − D) × VREF × GEA]

R5 = [2π × 5.8 × 0.08 × 200 kHz × 45 µF] / [0.733 × 1.212 × 190 µS]

R5 ≈ 155.5 kΩ

Practical first-pass choice: 154 kΩ or 158 kΩ, 1%.

# 9. Compensation Capacitor C5

C5 = Rₒ × Cₒ / (2 × R5)

C5 = 58 × 45 µF / (2 × 155.5 kΩ) ≈ 8.39 nF

Practical first-pass choice: 8.2 nF. Use a stable dielectric where practical.

# 10. High-Frequency Capacitor C6

C6 = RESR × Cₒ / R5

C6 = 0.003 × 45 µF / 155.5 kΩ ≈ 0.87 pF

Because the calculated value is below 10 pF, the datasheet permits C6 to be left open. Keep a footprint and mark it DNP for tuning.

# 11. Provisional Component Values

Item | Calculated value | Provisional schematic value
R5 | 155.5 kΩ | 154 kΩ or 158 kΩ, 1%
C5 | 8.39 nF | 8.2 nF
C6 | 0.87 pF | DNP / open; retain footprint
Selected crossover | 200 kHz | Provisional upper-limit design

# 12. Crossover-Frequency Sensitivity

Because R5 scales with crossover frequency and C5 changes inversely, the following alternatives are useful during review:

fC | R5 calculated | C5 calculated | C6 calculated
100 kHz | 77.75 kΩ | 16.78 nF | 1.74 pF
150 kHz | 116.62 kΩ | 11.19 nF | 1.16 pF
200 kHz | 155.50 kΩ | 8.39 nF | 0.87 pF

# 13. Required Validation Before PCB Release

• Choose the exact 22 µF capacitor part number and obtain effective capacitance at 5.8 V from the manufacturer DC-bias curve.

• Use the exact equivalent ESR of the populated parallel capacitor bank.

• Confirm the exact 2.2 µH inductor, including tolerance and inductance reduction under bias.

• Recalculate all values if CO, RESR, L, efficiency, switching frequency, or load changes.

• Verify loop stability using TI WEBENCH, a suitable small-signal simulation, or a measured Bode plot.

• Confirm greater than 45° phase margin and greater than 10 dB gain margin, as recommended by the datasheet.

• Place R5, C5, and the optional C6 immediately beside the COMP pin with a short, quiet ground return.

TPS610891 5.8 V Boost Stage - Provisional Design Calculation

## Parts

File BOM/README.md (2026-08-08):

Add the final bill of materials here after component selection is frozen.

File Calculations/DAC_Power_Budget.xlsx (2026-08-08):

Rail | Device | Quantity | Typical Current (mA) | Maximum Current (mA) | Total Maximum (mA) | Design Margin (30%) (mA) | Power @ Rail Voltage (W) | Notes
5VA | AK4499EX Analog / Reference | 1
3.3V | ESP32-S3 | 1
3.3V | AK4191 PVDD | 1
1.8V | AK4191 DVDD | 1
1.8V | AK4499EX TVDD | 1
1.2V | Core Supply (if used) | 1
+15V | OPA1612 | 1
-15V | OPA1612 | 1
+15V | OPA1622 | 1
-15V | OPA1622 | 1
5V/3.3V | Relay / Control | 1
5V | Miscellaneous | 1
 |  |  |  | Total Max Current (mA) |  | Total w/ Margin (mA)

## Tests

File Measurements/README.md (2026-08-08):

# Measurements

Reserved for rail ripple, FFT, THD+N, frequency response, output power, impedance, and thermal measurements.

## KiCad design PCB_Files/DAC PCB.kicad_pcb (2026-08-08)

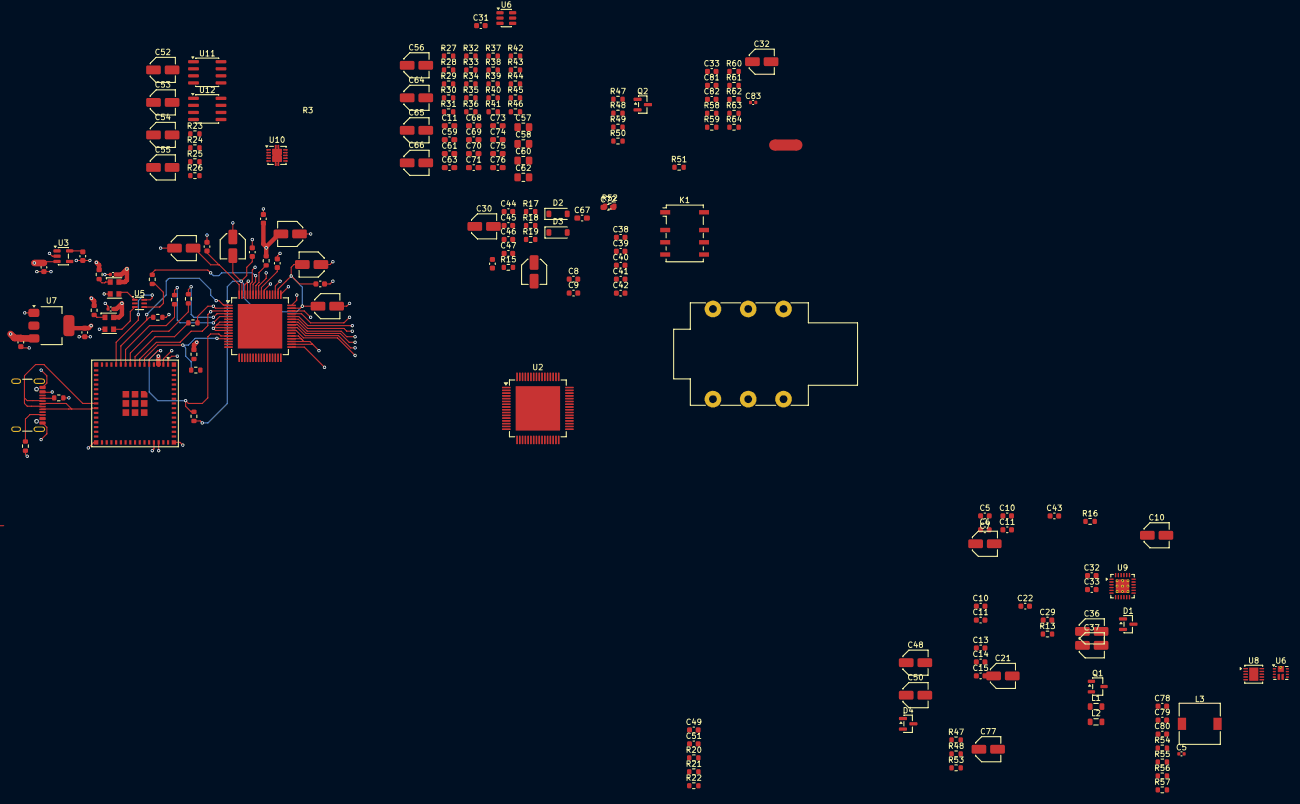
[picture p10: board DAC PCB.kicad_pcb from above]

Board: 4 copper layers, 184 parts (0 on the bottom side), 109 nets.

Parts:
C1, C2, C5#2: 0.1uF; C_0402_1005Metric
C3, C4, C5, C6, C8, C9, C10, C10#2, C11#2, C11#3, C12, C14, C16: 1uF; C_0603_1608Metric
C7, C10#3: 1uF; C_Elec_4x5.4
C11, C59, C61, C63: 100nF; C_0603_1608Metric_Pad1.08x0.95mm_HandSolder
C13, C15: 10uF; C_0603_1608Metric
C17, C19, C21, C26, C28: 10F; C_Elec_4x5.4
C18, C20, C22, C24, C27, C29, C33#2: 0.1F; C_0603_1608Metric
C23, C30, C32#2, C36, C50, C52, C54: 10uF; C_Elec_4x5.4
C25: 22F; C_0603_1608Metric
C31, C33, C34, C49, C51, C81: 0.1uF; C_0603_1608Metric
C32: 10F; C_0603_1608Metric
C35, C48: 2200uF; C_Elec_4x5.4
C37, C53, C55, C77: 0.1uF; C_Elec_4x5.4
C38, C40, C46: 4.7uF; C_0603_1608Metric
C39: 100nF; C_0603_1608Metric
C41, C45, C78, C79, C80, C82: 22uF; C_0603_1608Metric
C42: 6.8pF; C_0603_1608Metric
C43: 220nF; C_0603_1608Metric
C44: 7.5pF; C_0603_1608Metric
C47: 10nF; C_0603_1608Metric
C56, C64, C65, C66: 180pF; C_Elec_4x5.4
C57, C58, C60, C62: 10uF; C_0805_2012Metric_Pad1.18x1.45mm_HandSolder
C67, C68, C69, C70, C71, C72: 1nF; C_0603_1608Metric_Pad1.08x0.95mm_HandSolder
C73, C74, C75, C76: 470pF; C_0603_1608Metric_Pad1.08x0.95mm_HandSolder
C83: 8.5nF; C_0402_1005Metric
D1, D4: BZX84Cxx; SOT-23
D2, D3: D_Schottky; D_SOD-123
J1: USB_C_Receptacle_USB2.0_16P; USB_C_Receptacle_GCT_USB4105-xx-A_16P_TopMnt_Horizontal
J2: AudioJack3_Switch; Jack_6.35mm_Neutrik_NMJ6HHD2_Horizontal
K1: Relay_DPDT; Relay_DPDT_Omron_G6K-2F-Y
L1, L2: 4.7uH; L_0805_2012Metric
L3: 2.2uH; L_7.3x7.3_H4.5
NT1: NetTie_2; NetTie-2_SMD_Pad2.0mm
Q1: Q_PMOS_GSD; SOT-23-3
Q2: MMBT3904; SOT-23
R1, R2, R7, R8, R14, R21: 4700; R_0603_1608Metric
R3, R4, R5, R10: 33; R_0603_1608Metric
R6, R9, R13, R20, R22, R47, R48, R53, R63: 10000; R_0603_1608Metric
R11, R12: 5100; R_0603_1608Metric
R15, R32, R34, R37, R38: 100; R_0603_1608Metric
R16, R19: 1M; R_0603_1608Metric
R17: 130k; R_0603_1608Metric
R18: 121.2k; R_0603_1608Metric
R23, R24, R25, R26, R41, R42, R45, R46: 2000; R_0603_1608Metric
R27, R28, R29, R30: 360; R_0603_1608Metric
R31, R33, R35, R36: 500; R_0603_1608Metric
R39, R40, R43, R44: 5000; R_0603_1608Metric
R47#2, R48#2, R51, R52: 2.2; R_0603_1608Metric
R49: 2200; R_0603_1608Metric
R50: 100000; R_0603_1608Metric
R54: 66.8k; R_0603_1608Metric
R55: 378.5k; R_0603_1608Metric
R56: 100k; R_0603_1608Metric
R57: 1.03M; R_0603_1608Metric
R58: 30.1k; R_0603_1608Metric
R59: 249; R_0603_1608Metric
R60: 50; R_0603_1608Metric
R61: 49.9k; R_0603_1608Metric
R62: 700k; R_0603_1608Metric
R64: 150k; R_0603_1608Metric
U1, U2: Texas_TQFP-64-1EP_10x10mm_P0.5mm_EP8x8mm_Mask4.44x4.44mm
U3: AP2112K-1.2; SOT-23-5
U4: ESP32-S3-MINI-1U; ESP32-S2-MINI-1U
U5: 74LVC1G3157; SOT-363_SC-70-6
U6: TPS610891; Texas_VQFN-RNR0011A-11
U6#2: MCP4725xxx-xCH; SOT-23-6
U7: AMS1117-3.3; SOT-223-3_TabPin2
U8: LT3045xDD; DFN-10-1EP_3x3mm_P0.5mm_EP1.65x2.38mm
U9: TPS65131RGE; VQFN-24-1EP_4x4mm_P0.5mm_EP2.45x2.45mm_ThermalVias
U10: OPA1622; Texas_S-PVSON-N10
U11, U12: OPA1612AxD; SOIC-8_3.9x4.9mm_P1.27mm
Y1, Y2: XO32; Oscillator_SMD_EuroQuartz_XO32-4Pin_3.2x2.5mm

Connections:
+1.2V: C16.1, C17.2, C18.2, U1.64 (DVDD), U3.5 (VOUT)
+1.8V: C6.1, C7.2, C8.2, C9.2, C10#3.2, C13.1, C14.1, C15.1, C19.2, C20.2, C26.2, C27.2, C28.1, C29.1, C30.2, C31.2, C32#2.1, C33.1, C34.1, C35.1, C36.2, C37.2, C48.1, C49.1, C50.2, C51.2, C52.1, C53.1, C54.1, C55.1, C68.2, C69.1, C71.2, C72.1, C73.1, C75.1, C81.1, C82.2, D1.1 (A), D4.1 (A), J2.S, NT1.2, Q2.2 (E), R1.1, R2.1, R20.2, R21.1, R24.2, R26.2, R42.1, R45.1, R50.1, R58.2, R59.2, R60.2, R61.2, U1.47 (TVDD4), U1.50 (TVDD3), U1.63 (TVDD1), U2.2 (TVDD), U2.21 (VREFHR), U2.22 (VREFHR), U2.23 (VREFHR), U2.27 (VSSR), U2.28 (VSSR), U2.29 (VSSR), U2.34 (DEV1), U2.47 (DEV2), U2.52 (VSSL), U2.53 (VSSL), U2.54 (VSSL), U2.55 (VREFLL), U2.56 (VREFLL), U2.57 (VREFLL), U2.62 (AVSS), U2.64 (DVDD), U8.8 (GND), U8.11 (GND), U10.3 (GND)
+3.3V: C1.2, C2.2, C4.1, C11#3.1, C23.2, C24.2, R7.1, R8.1, R9.1, R13.1, R14.1, R53.1, R63.1, U4.3 (3V3), U7.2 (VO), Y1.4 (V+), Y2.4 (V+)
+5V: C3.1, C5.1, C10#2.1, C12.1, C32.2, C33#2.2, C40.1, C78.1, J1.A4 (VBUS), J1.A9 (VBUS), J1.B4 (VBUS), J1.B9 (VBUS), L3.1, Q1.2 (S), R15.1, U3.1 (VIN), U3.3 (EN), U6.9 (VIN), U6#2.3 (VDD), U7.3 (VI), U9.5 (INN), U9.6 (INN)
+5VA: C30.1, C31.1, C34.2, C35.2, C36.1, C37.1, C48.2, C49.2, C50.1, C51.1, C81.2, C82.1, D1.3 (K), D4.3 (K), R23.1, R25.1, R60.1, R62.1, U2.24 (VREFLR), U2.25 (VREFLR), U2.26 (VREFLR), U2.30 (VDDR), U2.31 (VDDR), U2.32 (VDDR), U2.49 (VDDL), U2.50 (VDDL), U2.51 (VDDL), U2.58 (VREFHL), U2.59 (VREFHL), U2.60 (VREFHL), U2.61 (AVDD), U6#2.1 (VOUT), U8.9 (OUTS), U8.10 (OUT)
+15V: C11.1, C41.1, C42.1, C57.1, C60.1, C61.1, D2.1 (K), R16.2, U9.23 (VPOS), U10.2 (V+), U10.8 (EN), U11.8 (V+), U12.8 (V+)
-15V: C44.2, C45.1, C58.1, C59.1, C62.1, C63.1, D3.2 (A), R19.1, U9.15 (VNEG), U10.4 (V-), U10.11 (V-), U11.4 (V-), U12.4 (V-)
/BCKO: U1.46 (BCKO), U2.4 (BCK)
/BICK: R3.2, U1.2 (BICK/DCLK/BCK)
/Base: Q2.1 (B), R49.2, R50.2
/D+: J1.A6 (D+), J1.B6 (D+), U4.24 (USB_D+)
/D-: J1.A7 (D-), J1.B7 (D-), U4.23 (USB_D-)
/ILeft+ve: R28.2, U2.42 (IOUTLP)
/ILeft-ve: R27.2, U2.45 (IOUTLN)
/IRight+ve: R30.2, U2.39 (IOUTRP)
/IRight-ve: R29.2, U2.36 (IOUTRN)
/LRCK: R4.2, U1.4 (LRCK/DSDR/DINR)
/Left+VE: C64.1, U2.43 (OPINLP), U11.6 (-)
/Left-VE: C56.1, U2.44 (OPINLN), U11.2 (-)
/MCLKEQ: R10.1, U1.59 (MCLK)
/MCLKO: U1.51 (MCLKO), U2.63 (MCLK)
/MCLKi: U4.12 (IO8), U5.6
/Muten: R22.1, U1.33 (MUTEN), U2.16 (MUTEN), U4.19 (IO15)
/PDN: R6.1, U1.1 (PDN), U4.11 (IO7)
/PG: R63.2, U4.21 (IO17), U8.4 (PG)
/Right+VE: C66.1, U2.38 (OPINRP), U12.6 (-)
/Right-VE: C65.1, U2.37 (OPINRN), U12.2 (-)
/SCL: R2.2, U1.12 (CCLK/SCL), U2.14 (LRSEL0/CCLK/SCL), U4.5 (IO1), U6#2.5 (SCL)
/SDA: R1.2, U1.13 (CDTI/SDA), U2.15 (LRSEL1/CDTI/SDA), U4.6 (IO2), U6#2.4 (SDA)
/SDATA: U1.3 (SDATA/DSDL/DINL), U4.7 (IO3)
/SDATA2: R5.2, U1.5 (SDTA2/DINL2)
/TVDD2: C21.1, C22.1, U1.60 (TVDD2)
/VOUTLN: C64.2, R28.1, R33.2, U11.7
/VOUTLP: C56.2, R27.1, R31.2, U11.1
/VOUTRP: C65.2, C66.2, R29.1, R30.1, R35.2, R36.2, U12.1, U12.7
/VoffL: C54.2, C55.2, R25.2, R26.1, U2.48 (VCOML), U11.3 (+), U11.5 (+)
/VoffR: C52.2, C53.2, R23.2, R24.1, U2.33 (VCOMR), U12.3 (+), U12.5 (+)
/in1: U1.45 (MBD1), U2.5 (MBD1)
/in2: U1.44 (MBD2), U2.6 (MBD2)
/in3: U1.43 (MBD3), U2.7 (MBD3)
/in4: U1.42 (MBD4), U2.8 (MBD4)
/in5: U1.41 (MBD5), U2.9 (MBD5)
/in6: U1.40 (MBD6), U2.10 (MBD6)
/in7: U1.39 (MBD7), U2.11 (MBD7)
GND: C1.1, C2.1, C3.2, C4.2, C5.2, C6.2, C10#2.2, C11.2, C11#3.2, C12.2, C16.2, C17.1, C18.1, C19.1, C20.1, C21.2, C22.2, C23.1, C24.1, C25.2, C26.1, C27.1, C28.2, C29.2, C32.1, C33#2.1, C38.2, C39.2, C40.2, C41.2, C43.2, C45.2, C46.2, C47.2, C57.2, C58.2, C59.2, C60.2, C61.2, C62.2, C63.2, C77.2, C78.2, C79.2, C80.2, C83.2, J1.A1 (GND), J1.A12 (GND), J1.B1 (GND), J1.B12 (GND), L2.1, NT1.1, R6.2, R11.2, R12.2, R17.1, R22.2, R47.1, R48.1, R56.2, R57.2, U1.7 (WCK), U1.8 (DSDL2), U1.9 (DSDR2), U1.10 (DCLK), U1.11 (CSN), U1.17 (PROG), U1.18 (AMUTE), U1.19 (CAD0), U1.20 (CAD1), U1.22 (TST2), U1.23 (TST1), U1.34 (NC), U1.35 (NC), U1.36 (NC), U1.37 (NC), U1.38 (NC), U1.48 (DVSS4), U1.49 (DVSS3), U1.55 (TST), U1.57 (PVSS), U1.61 (DVSS2), U1.62 (DVSS1), U3.2 (GND), U4.1 (GND), U4.2 (GND), U4.42 (GND), U4.43 (GND), U4.46 (GND), U4.47 (GND), U4.48 (GND), U4.49 (GND), U4.50 (GND), U4.51 (GND), U4.52 (GND), U4.53 (GND), U4.54 (GND), U4.55 (GND), U4.56 (GND), U4.57 (GND), U4.58 (GND), U4.59 (GND), U4.60 (GND), U4.61 (GND), U4.62 (GND), U4.63 (GND), U4.64 (GND), U4.65 (GND), U6.5 (GND), U6#2.2 (VSS), U6#2.6 (A0), U7.1 (GND), U9.2 (PGND), U9.3 (PGND), U9.19 (AGND), U9.25 (EP), Y1.2 (GND), Y2.2 (GND)
unnamed: C67.1, R31.1, R32.2
unnamed: C67.2, R33.1, R34.2
unnamed: C68.1, R32.1, R39.2
unnamed: C69.2, R34.1, R40.2
unnamed: C70.1, R35.1, R37.2
unnamed: C70.2, R36.1, R38.2
unnamed: C71.1, R37.1, R43.2
unnamed: C72.2, R38.1, R44.2
unnamed: C74.2, R41.1, R47#2.2, U10.9
unnamed: C76.2, R46.1, R48#2.2, U10.7
unnamed: C83.1, R64.2
unnamed: D2.2 (A), L1.2, U9.1 (INP), U9.24 (INP)
unnamed: D3.1 (K), L2.2, U9.13 (OUTN), U9.14 (OUTN)
unnamed: J1.A5 (CC1), R11.1
unnamed: J1.B5 (CC2), R12.1
unnamed: J2.R, R52.1
unnamed: J2.T, R51.1
unnamed: C38.1, L1.1, Q1.3 (D)
unnamed: Q1.1 (G), U9.7 (BSW)
unnamed: R10.2, U5.4
unnamed: R13.2, U1.21 (I2C)
unnamed: R14.2, U1.58 (PVDD)
unnamed: C25.1, U1.56 (VCOM)
unnamed: R47.2, U2.18 (DSEL2/CAD1)
unnamed: C13.2, C14.2, C15.2, U2.1 (DVSS)
unnamed: C10#3.1, U2.46 (EXTCLN)
unnamed: C9.1, U2.41 (EXTCLP)
unnamed: C7.1, U2.35 (EXTCRN)
unnamed: C8.1, U2.40 (EXTCRP)
unnamed: R20.1, U2.19 (PSN)
unnamed: R48.2, U2.17 (SC/CAD0)
unnamed: R21.2, U2.20 (VTSEL/I2C)
unnamed: C77.1, R53.2, U4.45 (EN)
unnamed: R9.2, U4.4 (IO0)
unnamed: R3.1, U4.8 (IO4)
unnamed: R4.1, U4.9 (IO5)
unnamed: R5.1, U4.10 (IO6)
unnamed: R49.1, U4.20 (IO16)
unnamed: C5#2.2, U6.10 (BOOT)
unnamed: R64.1, U6.4 (COMP)
unnamed: C79.1, U6.7 (EN)
unnamed: R55.2, R56.1, U6.3 (FB)
unnamed: R54.2, U6.1 (FSW)
unnamed: R57.1, U6.8 (ILIM)
unnamed: C5#2.1, L3.2, R54.1, U6.11 (SW)
unnamed: C80.1, U6.2 (VCC)
unnamed: C32#2.2, C33.2, R55.1, U6.6 (VOUT), U8.1 (IN), U8.2 (IN), U8.3 (EN/UV)
unnamed: R59.1, U8.5 (ILIM)
unnamed: R61.1, R62.2, U8.6 (PGFB)
unnamed: R58.1, U8.7 (SET)
unnamed: C46.1, U9.18 (CN)
unnamed: C47.1, U9.21 (CP)
unnamed: C39.1, R15.2, U9.4 (VIN), U9.8 (ENP), U9.9 (PSP), U9.10 (ENN), U9.11 (PSN)
unnamed: C44.1, R18.1, R19.2, U9.16 (FBN)
unnamed: C42.2, R16.1, R17.2, U9.22 (FBP)
unnamed: C43.1, R18.2, U9.17 (VREF)
unnamed: C73.2, R39.1, R42.2, U10.1 (+)
unnamed: C74.1, R40.1, R41.2, U10.10 (-)
unnamed: C75.2, R43.1, R45.2, U10.5 (+)
unnamed: C76.1, R44.1, R46.2, U10.6 (-)
unnamed: R7.2, Y1.1 (EN)
unnamed: U5.3, Y1.3 (OUT)
unnamed: R8.2, Y2.1 (EN)
unnamed: U5.1, Y2.3 (OUT)

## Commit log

2026-08-08 Fix image formatting in schematic section
    Updated schematic images section in README.
2026-08-08 Update image paths in README for schematics
2026-08-08 Fix project status and update schematic image links
    Updated project status and corrected image references in README.
2026-08-08 Change image paths to Schematics directory
    Updated image paths in README to reflect new directory structure.
2026-08-08 Update PCB progress images in README
